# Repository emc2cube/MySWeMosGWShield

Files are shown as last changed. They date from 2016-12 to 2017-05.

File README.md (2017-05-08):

MySWeMosGWShield
==========

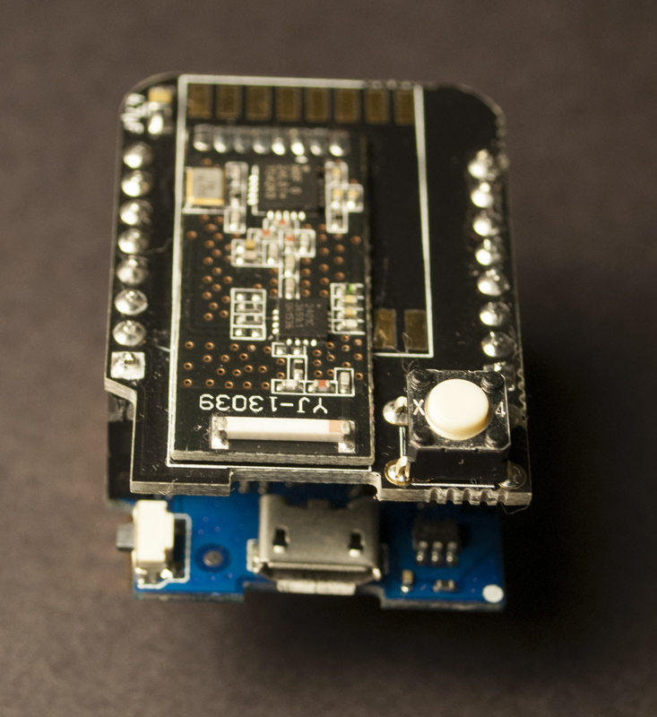
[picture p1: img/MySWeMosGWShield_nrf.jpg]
NRF24L01 GW on the WeMos

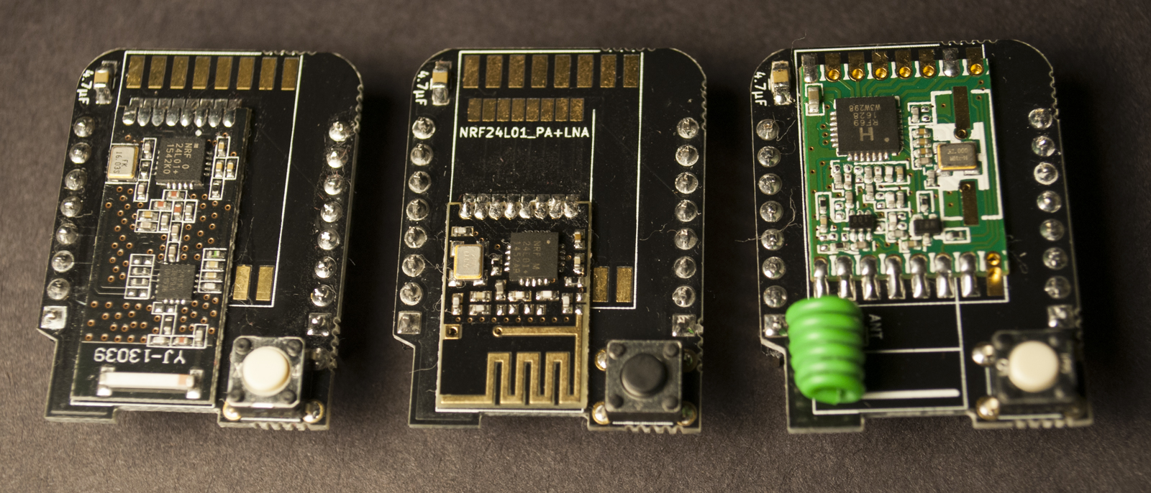
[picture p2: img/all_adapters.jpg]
All adapters

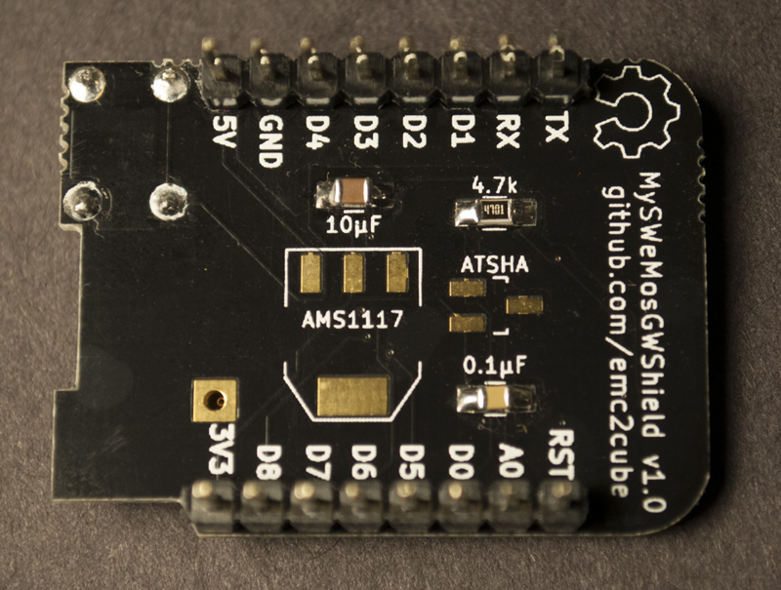
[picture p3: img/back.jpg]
PCB back view

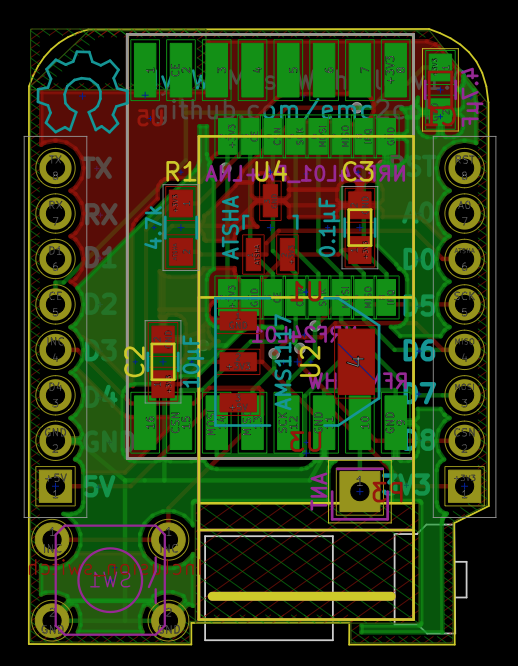
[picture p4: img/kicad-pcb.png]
KiCad view


Description
-----------

Simple [MySensors](http://www.mysensors.org) [WeMos Mini](https://www.wemos.cc/product/d1-mini-pro.html) gateway shield with support for 3 radio modules: SMD NRF24L01+, SMD PA+LNA NRF24L01+ or SMD RFM69HW.

Ordering
--------

Gerber files are included so you can order these PCB at your favorite PCB fab house and solder the few components yourself.
For an easy ordering process you can directly order these PCB without having to do anything else:
- [PCBs.io](https://PCBs.io/share/4QAjD) 4 for $5.52, black 1.2mm PCB, ENIG finish.
- [OSHPark.com](https://oshpark.com/shared_projects/59hasWWz) 3 for $6.90, purple 1.6mm PCB, ENIG finish.

Assembly
--------

Simply solder your favorite radio module to the corresponding trace and a 4.7 to 47µF SMD 0805 capacitor on the top side of the PCB.
It is also recommended to solder the 0.1µF and 10µF SMD 0805 capacitors but not required unless you add some of the optional components.

Radio module layout:
- NRF24L01 PA+LNA
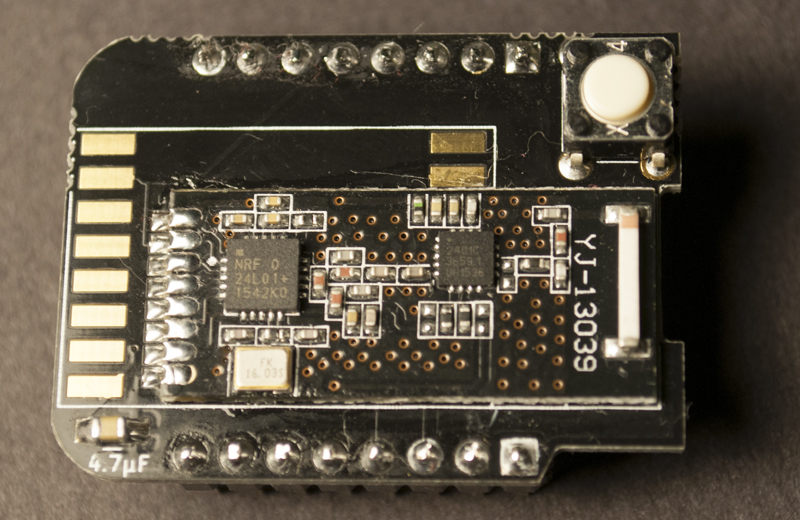
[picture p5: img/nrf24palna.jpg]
NRF24L01 PA+LNA shield

- NRF24L01
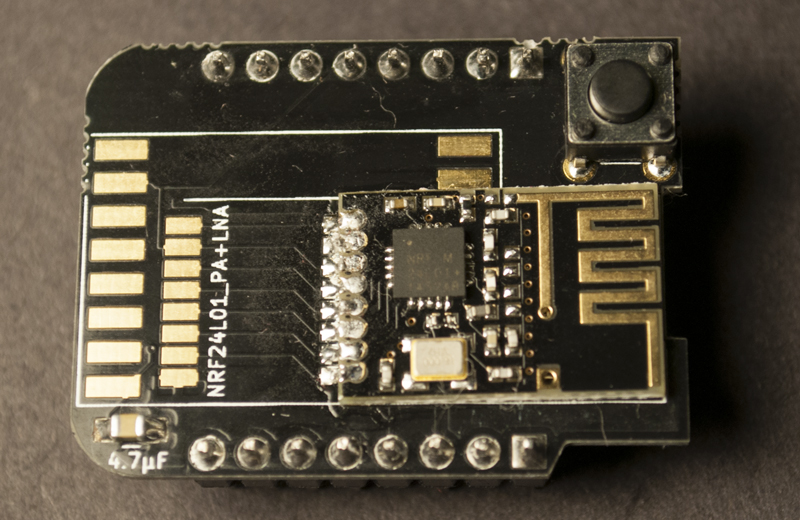
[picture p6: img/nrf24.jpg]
NRF24L01 shield

- RFM69HW
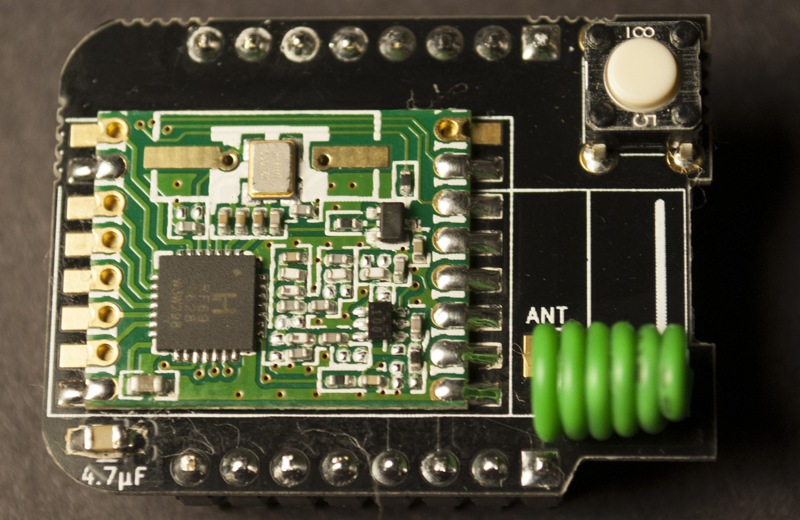
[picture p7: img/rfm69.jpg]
RFM69 shield


Optional components
-------------------

### 3.3V linear voltage regulator
You *should not* need to add this, but if you are using an amplified radio module (such as a PA+LNA NRF24L01+) you may experience Tx errors.
If the WeMos power regulator do not provide enough current for your radio you can add an additional AMS117 regulator between the 5V and 3.3V circuits and a 10µF SMD 0805 capacitor between 3.3V and GND.

### ATSHA204 module (unsupported?)
For security reason you can add a CryptAuthEE SHA256 chip. This will allow you to sign messages and will secure communications between the gateway and other nodes (this is not encryption, just signing).
If you decide to add the ATSHA204 chip you will need to add a 0.1µF SMD 0805 decoupling capacitor and 4.7kΩ SMD 0805 pull-up resistor.
Signing can also be done at the software level, without the chip if you decide to add this function later.
Currently ESP8266 MySensors gateway do not seem to support hardware encryption but it may work in a later release or if used as a node or repeater.
For complete reference see the detailled [MySensors Security & Signing guide](https://www.mysensors.org/about/signing)

### Inclusion mode button
If you have a compatible controller you can add an [inclusion mode button](https://www.mysensors.org/build/advanced_gateway#inclusion-mode-button).

Installation
-------

Plug the shield on top of your [WeMos Mini](https://www.wemos.cc/product/d1-mini-pro.html).
Do not forget to edit the various options of the [Arduino example code](https://github.com/emc2cube/MySWeMosGWShield/tree/master/Arduino/) before uploading it.

Arduino
-------

Included programs

### MySWeMosGWShield_SecurityPersonalizer
Adapted from [MySensors Security & Signing](https://www.mysensors.org/about/signing) SecurityPersonalizer sketch with pin assigned for this shield.

### MySWemosGatewayESP8266OTA
Gateway sketch exemple (NRF24L01, ESP8266 OTA and inclusion mode enabled)

Notes
-----

Shields are stackable and additional ones can be added on top / below the WeMos to introduce new functions / sensors to your gateway.
As a note, keep in mind that an ESP8266 tends to be warm while in use, a temperature probe won't be accurate if too close. 
For best radio performances it is recommended to have the radio shield on the topmost position.

Only a few pins are left to be used, depending on your configuration and the additional components added on the board:
- A0 (Analog input, max 3.3V input) is available if you don't use software signing.
- D0 (GPIO16, IO) is available if you don't add/use an ATSHA chip for hardware signing.
- D1 (GPIO5, IO, SCL) is always available.
- D3 (GPIO0, IO, 10k Pull-up) is available if you don't use an inclusion mode button.
- D4 (GPIO2, IO, 10k Pull-up, BUILTIN_LED) is available if you don't use flash leds on rx/tx/err.
- TX (GPIO1, TXD) is always available but used for serial communication.
- RX (GPIO3, RXD) is always available but used for serial communication.

Revision history
----------------

Version 1.0: Initial release.

Special Kicad libraries
---------------

This project use the [Kicad footprints and templates for WeMos D1 mini board](https://github.com/jerome-labidurie/d1_mini_kicad) library.

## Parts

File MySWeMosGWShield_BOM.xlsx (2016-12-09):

Quantity | Reference | Value | Package | Manufacturer | Manufacturer P/N | Mouser P/N | Comment | Aliexpress or Ebay link
2 | P1, P2 | CONN_01X08 | WeMos D1 mini Pin Header | WeMos | D1 mini pro |  |  | https://www.aliexpress.com/item/WEMOS-D1-mini-Pro-16M-bytes-external-antenna-connector-ESP8266-WIFI-Internet-of-Things-development-board/32724692514.html
1 | P3 | ANT | Antenna connector
1 | U1 | NRF24L01_PA+LNA | NRF24L01-SMD PA+LNA radio module |  |  |  | U1 or U3 or U5 | https://www.aliexpress.com/item/5pcs-lot-SMD-NRF24L01-1100-meter-long-distance-NRF24L01-PA-LNA-SMD-wireless-modules-1100meters-in/32367250849.html
1 | U2 | AMS1117 | SOT-223 | Texas Instruments | LM1117MP-3.3/NOPB | 926-LM1117MP-3.3NOPB |  | https://www.aliexpress.com/item/Free-Shipping-100PCS-Original-AMS1117-3-3-AMS1117-3-3V-AMS1117-LM1117-1117-Voltage-Regulator-We/32351569056.html
1 | U3 | NRF24L01 | NRF24L01-SMD radio module |  |  |  | U1 or U3 or U5
1 | U4 | ATSHA | SOT-23 | Atmel | ATSHA204A-STUCZ-T | 566-ATSHA204ASTUCZ-T | Optional, for signing
1 | U5 | RFM69HW | RFM69HW-SMD |  |  |  | U1 or U3 or U5 | https://www.aliexpress.com/item/New-RFM69HW-868Mhz-HopeRF-Wireless-Transceiver-RFM69HW-868S2-For-Remote-HM/32707574282.html
1 | R1 | 4.7k | SMD 0805 | Bourns | CR0805-JW-472ELF | 652-CR0805-JW-472ELF |  | http://www.aliexpress.com/item/100pcs-lot-SMD-Chip-Resistor-1-0805-4-7K-4700-OHMS-1-8W-100-YAGEO-New/32570155447.html
1 | C1 | 4.7µF | SMD 0805 | Murata | GRM21BR61C475KA88K | 81-GRM21BR61C475KA8K |  | http://www.aliexpress.com/item/1LOT-100PCS-Chip-Capacitors-4-7uF-475K-16V-10-0805-Package0805-2012-Metric/32561376020.html
1 | C2 | 10µF | SMD 0805 | Murata | GRM21BR6YA106KE43L | 81-GRM21BR6YA106KE3L |  | https://www.aliexpress.com/item/1849449/32560458041.html
1 | C3 | 0.1µF | SMD 0805 | Murata | GRM21R71C104JA01D | 81-GRM21R71C104JA01D |  | http://www.aliexpress.com/item/1LOT-100PCS-Chip-Capacitors-0-1uF-104K-16V-10-0805-Package0805-2012-Metric/32560085454.html
1 | SW1 | Inclusion_switch | Tactile Switches 6X6 Flat | Omron Electronics | B3F-1000 | 653-B3F-1000 |  | https://www.aliexpress.com/item/150-Pcs-Tact-Switch-6x6x4-3-h-Iron-Foot-Insert-Feature-Momentary-Contact-4-Pins-DC/32696256274.html

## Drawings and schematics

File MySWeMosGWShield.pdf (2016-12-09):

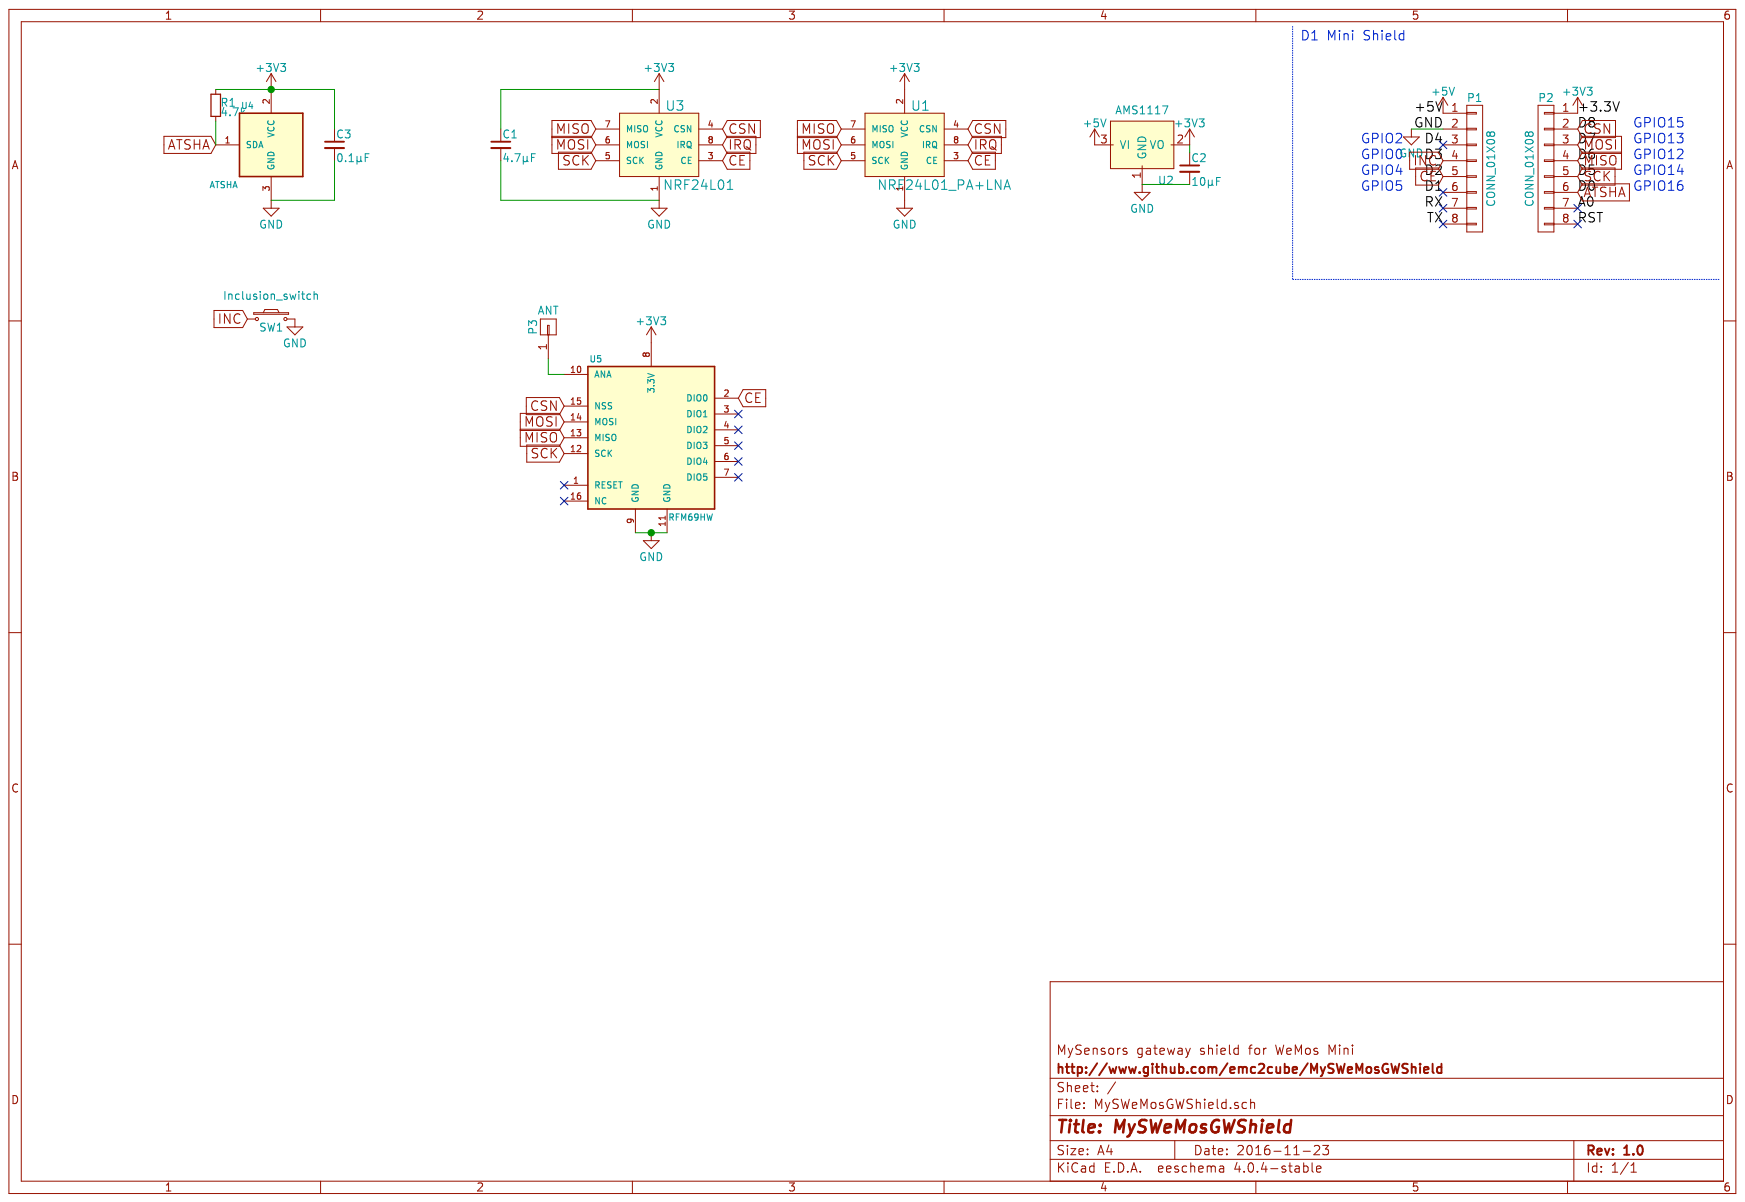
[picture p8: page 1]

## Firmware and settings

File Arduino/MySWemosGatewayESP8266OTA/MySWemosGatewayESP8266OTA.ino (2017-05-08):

/**
   The MySensors Arduino library handles the wireless radio link and protocol
   between your home built sensors/actuators and HA controller of choice.
   The sensors forms a self healing radio network with optional repeaters. Each
   repeater and gateway builds a routing tables in EEPROM which keeps track of the
   network topology allowing messages to be routed to nodes.

   Created by Henrik Ekblad <henrik.ekblad@mysensors.org>
   Copyright (C) 2013-2015 Sensnology AB
   Full contributor list: https://github.com/mysensors/Arduino/graphs/contributors

   Documentation: http://www.mysensors.org
   Support Forum: http://forum.mysensors.org

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
 *******************************

   Make sure to fill in your ssid and WiFi password below for ssid & pass.
   If you decide to enable ESP8266 OTA update it is recommended to set a password
   Hardware SHA204 signing is probably not supported for ESP8266 gateways but may work if used as a node (untested)
*/

// ** WiFi and network configuration **
#define MY_ESP8266_SSID "MySSID"
#define MY_ESP8266_PASSWORD "MyVerySecretPassword"

// Set the hostname for the WiFi Client. This is the hostname
// it will pass to the DHCP server if not static.
#define MY_ESP8266_HOSTNAME "MySWeMosGWShield"

// Enable UDP communication
//#define MY_USE_UDP

// Enable MY_IP_ADDRESS here if you want a static ip address (no DHCP)
//#define MY_IP_ADDRESS 192,168,178,87

// If using static ip you need to define Gateway and Subnet address as well
#define MY_IP_GATEWAY_ADDRESS 192,168,178,1
#define MY_IP_SUBNET_ADDRESS 255,255,255,0

// The port to keep open on node server mode
#define MY_PORT 5003

// How many clients should be able to connect to this gateway (default 1)
#define MY_GATEWAY_MAX_CLIENTS 2

// Controller ip address. Enables client mode (default is "server" mode).
// Also enable this if MY_USE_UDP is used and you want sensor data sent somewhere.
//#define MY_CONTROLLER_IP_ADDRESS 192, 168, 178, 68


// ** OTA updates configuration **
// Enable OTA updates for ESP8266 based gateway
#define ESP8266_OTA

// Define password for OTA updates (recommended but optional)
//#define ESP8266_OTA_PASSWORD "MySuperSecretOTAPassword"


// ** MySensors Radio configuration **
// Enables and select radio type (if attached)
#define MY_RADIO_NRF24
//#define MY_RADIO_RFM69

// RF24 settings
// Use custom RF24 channel (default 76)
//#define MY_RF24_CHANNEL 42
// Decrease RF24 power transmission, useful to test in case of Tx problems.
// If your problem is fixed consider adding the 5V to 3.3V voltage regulator
//#define MY_RF24_PA_LEVEL RF24_PA_LOW
// Enables RF24 encryption (all nodes and gateway must have this enabled, and all must be personalized with the same AES key)
//#define MY_RF24_ENABLE_ENCRYPTION

// RF69 settings
// RFM69 Frequency, default = 868MHz
#define MY_RFM69_FREQUENCY RF69_868MHZ // RFM69 frequency to use (RF69_433MHZ for 433MHz, RF69_868MHZ for 868MHz or RF69_915MHZ for 915MHz)
// RFM69 Network ID. Use the same for all nodes that will talk to each other, default = 100
//#define MY_RFM69_NETWORKID     42
// Enables RFM69 encryption (all nodes and gateway must have this enabled, and all must be personalized with the same AES key)
//#define MY_RFM69_ENABLE_ENCRYPTION
// Disable this if you're not running the RFM69HW model (RFM69HW is recommended on the gateway for better coverage)
#define MY_IS_RFM69HW


// ** Mysensors additional functions **
// Enable inclusion mode
#define MY_INCLUSION_MODE_FEATURE

// Enable Inclusion mode button on gateway
#define MY_INCLUSION_BUTTON_FEATURE
// Set inclusion mode duration (in seconds)
#define MY_INCLUSION_MODE_DURATION 60
// Digital pin used for inclusion mode button
#define MY_INCLUSION_MODE_BUTTON_PIN  D3  // GPIO 0

// Software signing settings
//#define MY_SIGNING_SOFT
#define MY_SIGNING_SOFT_RANDOMSEED_PIN A0

// Hardware signing settings (currently unsupported?)
//#define MY_SIGNING_ATSHA204
#define MY_SIGNING_ATSHA204_PIN D0  // GPIO 16

// General signing settings
// Enable this if you want destination node to sign all messages sent to this gateway.
//#define MY_SIGNING_REQUEST_SIGNATURES
// Enable node whitelisting
//#define MY_SIGNING_NODE_WHITELISTING {{.nodeId = GATEWAY_ADDRESS,.serial = {0x09,0x08,0x07,0x06,0x05,0x04,0x03,0x02,0x01}}}

// Flash leds on rx/tx/err
// Set blinking period
#define MY_DEFAULT_LED_BLINK_PERIOD 300

// Led pins used if blinking feature is enabled above
// LED_BUILTIN, the on board LED is used (D4, GPIO 2)
#define MY_DEFAULT_ERR_LED_PIN LED_BUILTIN // Error led pin
#define MY_DEFAULT_RX_LED_PIN  LED_BUILTIN // Receive led pin
#define MY_DEFAULT_TX_LED_PIN  LED_BUILTIN // Transmit led pin

// Enable debug prints to serial monitor
//#define MY_DEBUG


// **************************************//
// You probably don't need to edit below //
// **************************************//

#include <EEPROM.h>
#include <SPI.h>
#if defined ESP8266_OTA
#include <ArduinoOTA.h>
#endif
#if defined(MY_USE_UDP)
#include <WiFiUDP.h>
#else
#include <ESP8266WiFi.h>
#endif

// Set the gateway type to ESP8266
#define MY_GATEWAY_ESP8266

// Disable serial and allow TX and RX to be used as GPIO when debug is disabled
#ifndef MY_DEBUG
#define MY_DISABLED_SERIAL
#endif

// Enable signing related debug prints to serial monitor if debug and signing are both enabled
#if ((defined MY_DEBUG) && ( defined MY_SIGNING_SOFT || defined MY_SIGNING_ATSHA204))
#define MY_DEBUG_VERBOSE_SIGNING
#endif

// Define RFM69 pins to match PCB traces
#if defined MY_RADIO_RFM69
#define MY_RF69_IRQ_PIN D2  // GPIO 4
#define MY_RF69_IRQ_NUM D2  // GPIO 4
#define MY_RF69_SPI_CS  D8  // GPIO 15
#endif

#define ARDUINO_ARCH_ESP8266

#include <MySensors.h>


void setup() {
  // Executed once at boot
#if defined ESP8266_OTA
#if defined MY_DEBUG
  Serial.println("");
  Serial.println("ESP8266 OTA enabled");
#endif

#if defined ESP8266_OTA_PASSWORD
#if defined MY_DEBUG
  Serial.println("OTA Password set");
#endif
  ArduinoOTA.setPassword(ESP8266_OTA_PASSWORD);
#endif

  ArduinoOTA.setHostname(MY_ESP8266_HOSTNAME);
  ArduinoOTA.onStart([]() {
    Serial.println("ArduinoOTA start");
  });
  ArduinoOTA.onEnd([]() {
    Serial.println("\nArduinoOTA end");
  });
  ArduinoOTA.onProgress([](unsigned int progress, unsigned int total) {
    Serial.printf("OTA Progress: %u%%\r", (progress / (total / 100)));
  });
  ArduinoOTA.onError([](ota_error_t error) {
    Serial.printf("Error[%u]: ", error);
    if (error == OTA_AUTH_ERROR) Serial.println("Auth Failed");
    else if (error == OTA_BEGIN_ERROR) Serial.println("Begin Failed");
    else if (error == OTA_CONNECT_ERROR) Serial.println("Connect Failed");
    else if (error == OTA_RECEIVE_ERROR) Serial.println("Receive Failed");
    else if (error == OTA_END_ERROR) Serial.println("End Failed");
  });
  ArduinoOTA.begin();
#endif

#if defined MY_DEBUG
  if (WiFi.status() != WL_CONNECTED) {
    Serial.println("Not connected to WiFi");
  } else {
    Serial.println("");
    Serial.println("-- STA (client) informations --");
    Serial.print("Hostname: ");
    Serial.println(WiFi.hostname());
    Serial.print("Connected to: ");
    Serial.print(WiFi.SSID());
    Serial.print(" (");
    Serial.print(WiFi.BSSIDstr());
    Serial.print("), ");
    Serial.print(WiFi.RSSI());
    Serial.println("dBm");
    Serial.print("IP address: ");
    Serial.println(WiFi.localIP());
    Serial.print("Gateway address: ");
    Serial.println(WiFi.gatewayIP());
    Serial.print("Subnet mask: ");
    Serial.println(WiFi.subnetMask());
    Serial.print("MAC STA address: ");
    Serial.println(WiFi.macAddress());
    Serial.println("-- AP (server) informations --");
    Serial.print("Soft IP address: ");
    Serial.println(WiFi.softAPIP());
    Serial.print("MAC AP address: ");
    Serial.println(WiFi.softAPmacAddress());
    Serial.println("----");
    Serial.println("");
  }
#endif
}


void presentation() {
  // Present locally attached sensors here
}


void loop() {
  // Send locally attech sensors data here
#if defined ESP8266_OTA
  ArduinoOTA.handle();
#endif
}

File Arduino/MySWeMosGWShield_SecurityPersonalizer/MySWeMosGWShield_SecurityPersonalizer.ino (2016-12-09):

/*
 * The MySensors Arduino library handles the wireless radio link and protocol
 * between your home built sensors/actuators and HA controller of choice.
 * The sensors forms a self healing radio network with optional repeaters. Each
 * repeater and gateway builds a routing tables in EEPROM which keeps track of the
 * network topology allowing messages to be routed to nodes.
 *
 * Created by Henrik Ekblad <henrik.ekblad@mysensors.org>
 * Copyright (C) 2013-2015 Sensnology AB
 * Full contributor list: https://github.com/mysensors/Arduino/graphs/contributors
 *
 * Documentation: http://www.mysensors.org
 * Support Forum: http://forum.mysensors.org
 *
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
 *******************************
 */
/**
 * @ingroup MySigninggrp
 * @{
 * @file SecurityPersonalizer.ino
 * @brief Security personalization sketch
 *
 * REVISION HISTORY
 *  - See git log (git log libraries/MySensors/examples/SecurityPersonalizer/SecurityPersonalizer.ino)
 */

/**
 * @example SecurityPersonalizer.ino
 * This sketch will personalize either none-volatile memory or ATSHA204A for security functions
 * available in the MySensors library.
 *
 * For ATSHA204A:
 * It will write factory default settings to the configuration zone
 * and then lock it.<br>
 * It will then either<br>
 * -# Generate a random value to use as a key which will be stored in
 * slot 0. The key is printed on UART (115200) in clear text for the user to be
 * able to use it as a user-supplied key in other personalization executions
 * where the same key is needed.
 * -# Use a user-supplied value to use as a key which will be stored in
 * slot 0.
 * Finally it will lock the data zone.
 *
 * By default, no locking is performed. User have to manually enable the flags that
 * turn on the locking. Furthermore, user have to send a SPACE character on serial
 * console when prompted to do any locking. On boards that does not provide UART
 * input it is possible to configure the sketch to skip this confirmation.
 * Default settings use ATSHA204A on @ref MY_SIGNING_ATSHA204_PIN.
 *
 * For Soft signing:
 * It will<br>
 * -# Generate a random value to use as a key which will be stored in EEPROM.
 * The key is printed on UART (115200) in clear text for the user to be ablle to
 * use it as a user-supplied key in other personalization executions where the same
 * key is needed.
 * -# Use a user-supplied value to use as a key which will be stored in EEPROM.
 * -# Generate a random value to use as a serial number which will be stored in EEPROM.
 * The serial number is printed on UART (115200) in clear text for the user to be ablle to
 * use it as a user-supplied serial number in other personalization executions where the
 * serial is needed (typically for a whitelist).
 * -# Use a user-supplied value to use as a serial which will be stored in EEPROM.
 *
 * For Encryption support:
 * -# Generate a random value to use as a AES key which will be stored in EEPROM.
 * The AES key is printed on UART (115200) in clear text for the user to be ablle to
 * use it as a user-supplied AES key in other personalization executions where the
 * AES key is needed (typically for RF encryption).
 * -# Use a user-supplied value to use as a AES key which will be stored in EEPROM.
 *
 * Personalizing EEPROM or ATSHA204A still require the appropriate configuration of the
 * library to actually have an effect. There is no problem personalizing EEPROM and
 * ATSHA204A at the same time. There is however a security risk with using the same
 * data for EEPROM and ATSHA204A so it is recommended to use different serial and HMAC
 * keys on the same device for ATSHA204A vs soft signing settings.
 *
 * Details on personalization procedure is given in @ref personalization.
 */

#include "sha204_library.h"
#include "sha204_lib_return_codes.h"
#define MY_CORE_ONLY
#define MY_SIGNING_ATSHA204_PIN D0
#define MY_SIGNING_SOFT_RANDOMSEED_PIN A0
#include <MySensors.h>

// Doxygen specific constructs, not included when built normally
// This is used to enable disabled macros/definitions to be included in the documentation as well.
#if DOXYGEN
#define LOCK_CONFIGURATION
#define LOCK_DATA
#define SKIP_KEY_STORAGE
#define USER_KEY
#define SKIP_UART_CONFIRMATION
#define USE_SOFT_SIGNING
#define STORE_SOFT_KEY
#define USER_SOFT_KEY
#define STORE_SOFT_SERIAL
#define USER_SOFT_SERIAL
#define STORE_AES_KEY
#define USER_AES_KEY
#endif

/**
 * @def LOCK_CONFIGURATION
 * @brief Uncomment this to enable locking the configuration zone.
 *
 * It is still possible to change the key, and this also enable random key generation.
 * @warning BE AWARE THAT THIS PREVENTS ANY FUTURE CONFIGURATION CHANGE TO THE CHIP
 */
//#define LOCK_CONFIGURATION

/**
 * @def LOCK_DATA
 * @brief Uncomment this to enable locking the data zone.
 *
 * It is not required to lock data, key cannot be retrieved anyway, but by locking
 * data, it can be guaranteed that nobody even with physical access to the chip,
 * will be able to change the key.
 * @warning BE AWARE THAT THIS PREVENTS THE KEY TO BE CHANGED
 */
//#define LOCK_DATA

/**
 * @def SKIP_KEY_STORAGE
 * @brief Uncomment this to skip key storage (typically once key has been written once)
 */
#define SKIP_KEY_STORAGE

/**
 * @def USER_KEY
 * @brief Uncomment this to skip key generation and use @ref user_key_data as key instead.
 */
//#define USER_KEY

/**
 * @def SKIP_UART_CONFIRMATION
 * @brief Uncomment this for boards that lack UART
 *
 * @b Important<br> No confirmation will be required for locking any zones with this configuration!
 * Also, key generation is not permitted in this mode as there is no way of presenting the generated key.
 */
//#define SKIP_UART_CONFIRMATION

/**
 * @def USE_SOFT_SIGNING
 * @brief Uncomment this to store data to EEPROM instead of ATSHA204A
 */
//#define USE_SOFT_SIGNING

/**
 * @def STORE_SOFT_KEY
 * @brief Uncomment this to store soft HMAC key to EEPROM
 */
//#define STORE_SOFT_KEY

/**
 * @def USER_SOFT_KEY
 * @brief Uncomment this to skip soft HMAC key generation and use @ref user_soft_key_data as HMAC key instead.
 */
//#define USER_SOFT_KEY

/**
 * @def STORE_SOFT_SERIAL
 * @brief Uncomment this to store soft serial to EEPROM
 */
//#define STORE_SOFT_SERIAL

/**
 * @def USER_SOFT_SERIAL
 * @brief Uncomment this to skip soft serial generation and use @ref user_soft_serial as serial instead.
 */
//#define USER_SOFT_SERIAL

/**
 * @def STORE_AES_KEY
 * @brief Uncomment this to store AES key to EEPROM
 */
//#define STORE_AES_KEY

/**
 * @def USER_AES_KEY
 * @brief Uncomment this to skip AES key generation and use @ref user_aes_key as key instead.
 */
//#define USER_AES_KEY

#if defined(SKIP_UART_CONFIRMATION) && !defined(USER_KEY)
#error You have to define USER_KEY for boards that does not have UART
#endif
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

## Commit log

2016-12-09 Initial release
    Initial release (not fully tested for RFM69)
    [MySWeMosGWShield-B.Cu.gbr, MySWeMosGWShield-B.Mask.gbr, MySWeMosGWShield-B.SilkS.gbr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]
2017-01-30 RFM69 fix
    Fix for RFM69 radio, adding MY_RF69_IRQ_NUM definition seems to be
    mandatory.
    [MySWemosGatewayESP8266OTA.ino]

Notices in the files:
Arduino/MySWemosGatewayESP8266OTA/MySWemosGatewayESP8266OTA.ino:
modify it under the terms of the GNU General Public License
